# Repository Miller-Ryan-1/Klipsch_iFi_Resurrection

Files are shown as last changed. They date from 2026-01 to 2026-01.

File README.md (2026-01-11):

# Klipsch iFi Resurrection  
### Salvaging a Klipsch iFi 2.1 System & Adding Bluetooth

---

## Summary

This project revives a broken Klipsch iFi 2.1 speaker system whose proprietary iPod dock failed, rendering the entire system unusable. By emulating the dock’s logic using a simple microcontroller and discrete components, the system powers on and functions normally again.

Bluetooth audio support was added as a modern input, restoring full usability while preserving the system’s original (and still outstanding) sound quality.

This repository contains:
- Arduino firmware
- Hardware wiring details
- Reference documentation
- STL files for a custom 3D-printed enclosure
- Build photos from two hardware revisions

---

## Background

I’ve been hauling this Klipsch iFi system around since mid-2006. I originally intended to buy a Bose SoundDock, but a Best Buy salesman directed me toward the Klipsch instead. It was more expensive (about $100 more), and far heavier, but sounded dramatically better. And it got LOUD.

The system followed me across continents. Fans of *Club Jesuitenfahrt 7* in Amberg, Germany would dance and drank the night away to these speakers.

Eventually, the proprietary dock became the system’s Achilles’ heel. Newer iPhones no longer fit properly, and when the dock finally failed electrically, the entire subwoofer refused to power on—even when using the auxiliary input. Without a working dock, the system was bricked.

There is no public documentation on how to repair or bypass this dock logic. This was a one-off product for Klipsch, and very little information was ever released.

Using modern LLMs, I was finally able to identify the key control IC (LM1973) and replicate the dock’s behavior externally. This repository documents that solution.

---

## Repository Structure

```text
Klipsch_iFi_Resurrection/
│
├── klipsch_reviver/
│   └── klipsch_reviver.ino
│
├── case_stil_files/
│   ├── Klipsch_Case_Base.stl
│   └── Klipsch_Case_Cover.stl
│
├── pictures/
│   ├── DIN-9_mockup.JPG
│   ├── DIN-9_wires.JPG
│   ├── main_board.JPG
│   ├── sub_insides.JPG
│   ├── v1.JPG
│   ├── v1_closeup.JPG
│   ├── v1_on.JPG
│   ├── v2.JPG
│   └── v2_connections.JPG
│
├── DIN-9 Pinout.pdf
├── LM1973_info.pdf
└── README.md
```

---

## Bill of Materials (BOM)

| Qty | Component (and link to example) |
|----:|:---|
| 1 | [Arduino-compatible 5 V microcontroller](https://www.amazon.com/AYWHP-ATmega328P-Microcontroller-Compatible-Arduino/dp/B0DFGQW2ZY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) |
| 2 | 100 kΩ resistors |
| 6 | 10 kΩ resistors |
| 2 | 100 Ω resistors |
| 1 | 1 kΩ resistor |
| 1 | 10 µF electrolytic capacitor |
| 2 | 0.1 µF ceramic capacitors |
| 1 | 47 nF ceramic capacitor |
| 2 | 1 nF ceramic capacitors |
| 1 | [Male DIN-9 cable](https://www.amazon.com/dp/B0C9QGQHK2?ref_=ppx_hzsearch_conn_dt_b_fed_asin_title_1&th=1) |
| 1 | [12 V → 5 V buck converter](https://www.amazon.com/dp/B08VHZJ3C8?ref_=ppx_hzsearch_conn_dt_b_fed_asin_title_1&th=1) |
| 4 | [Normally-open momentary push buttons](https://www.amazon.com/DAOKI-Miniature-Momentary-Tactile-Quality/dp/B01CGMP9GY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) |
| 1 | [LED (power indicator)](https://www.amazon.com/OWOFYDR-diffused-Electronic-Component-Indicator/dp/B0DHX8Q58F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) |
| 1 | [Breadboard](https://www.amazon.com/ELEGOO-Breadboard-Solderless-Breadboards-Electronics/dp/B0CYPVMK9J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) |
| 1 | [Ferrite core](https://www.amazon.com/20pcs-Clip-Ferrite-Suppressor-Diameter/dp/B0CSXZWGD6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) |
| 1 | Project enclosure |

**Optional (but recommended):**
- Bluetooth audio module (with external antenna connector)
- Bluetooth antenna (external)
- RCA-to-3.5 mm or 3.5 mm-to-3.5 mm audio cable

*$$ Note: The total cost is hard to pinpoint, since many components cannot be purchased in single quantities, but it probably cost me less than $40, to include Bluetooth Audio Module and raw PLA filament (material I used for the box).*

---

## Procedure

### 0) Optional: Inspect the Subwoofer Internals

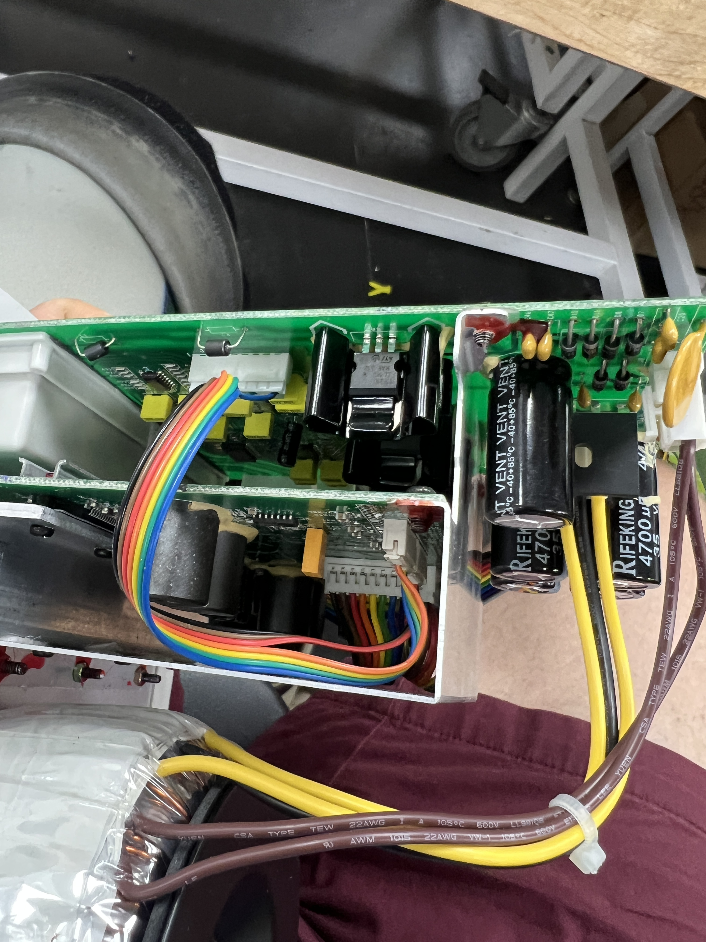
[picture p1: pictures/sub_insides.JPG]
Subwoofer internals


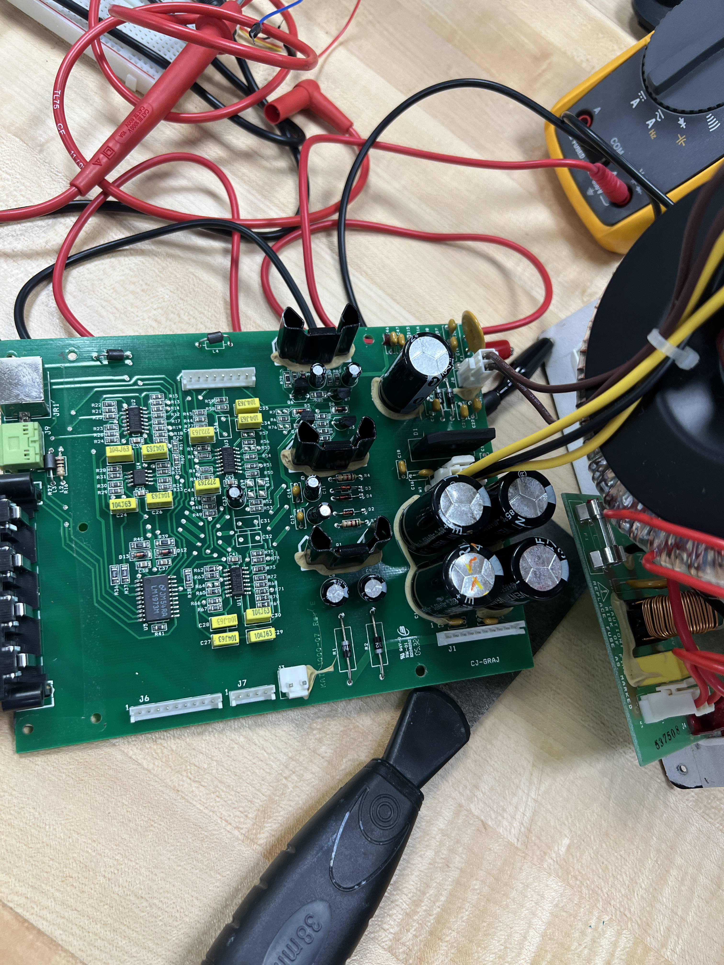
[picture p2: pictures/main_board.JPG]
Main board
  

I initially opened the subwoofer to understand the signal flow and verify component health—especially the LM1973 digital volume control IC that the dock communicates with.

In hindsight, this step was unnecessary; all internal components were functional.

**Warning:** The subwoofer contains large capacitors capable of delivering a severe shock. If opening:
- Unplug and allow the unit to sit for several hours
- Discharge large capacitors with an insulated tool
- Avoid touching exposed circuitry

---

### 1) Prepare the DIN-9 Cable

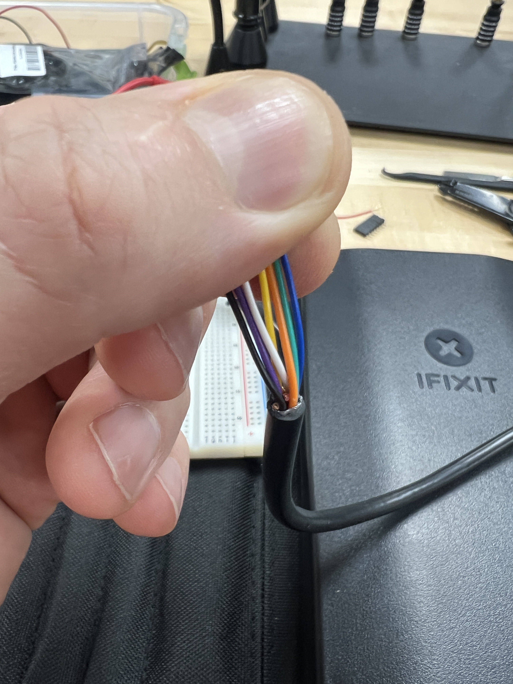
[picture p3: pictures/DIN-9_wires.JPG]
DIN-9 wires


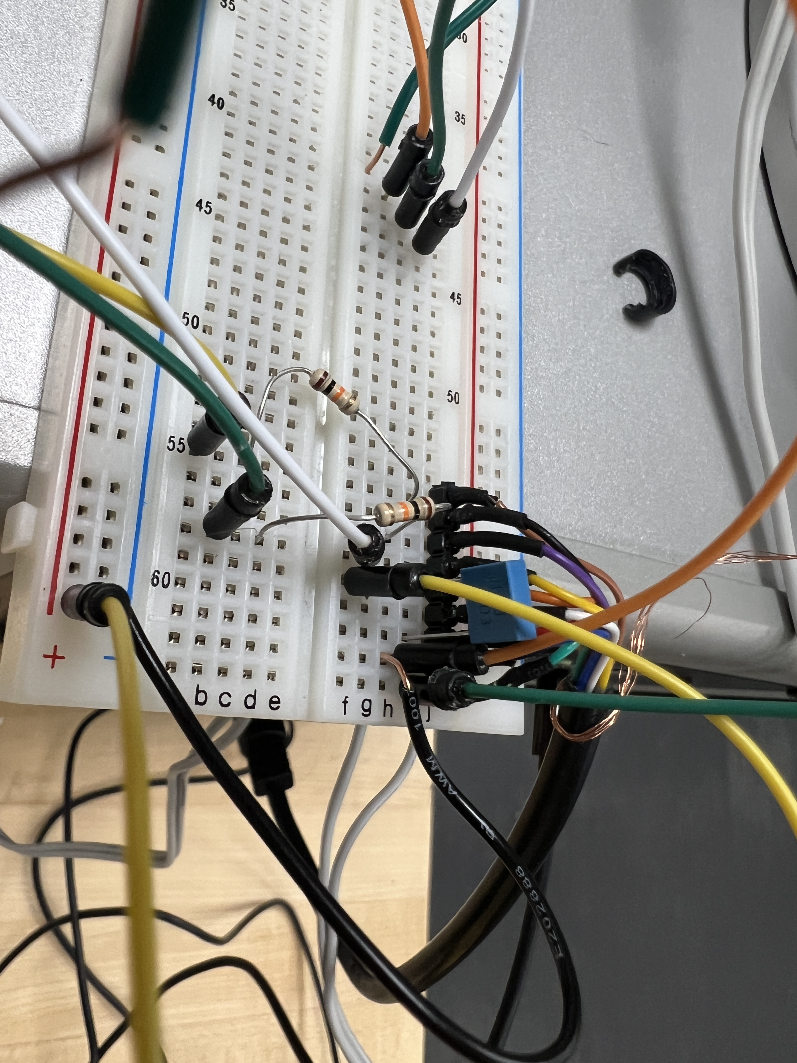
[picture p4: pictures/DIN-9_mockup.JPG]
DIN-9 mockup
  

Cut the DIN-9 cable approximately 12 inches from the male plug. Strip the outer sheath to expose:
- 9 internal conductors
- Foil shielding
- Bare braided ground wire

Keep exposed wire lengths as short as possible to minimize noise.

Use a multimeter to identify each conductor’s pin. Do **not** rely on wire colors.  

Speaking of colors, the colors in the diagram below is NOT related to wire colors, but rather functional pin groupings.

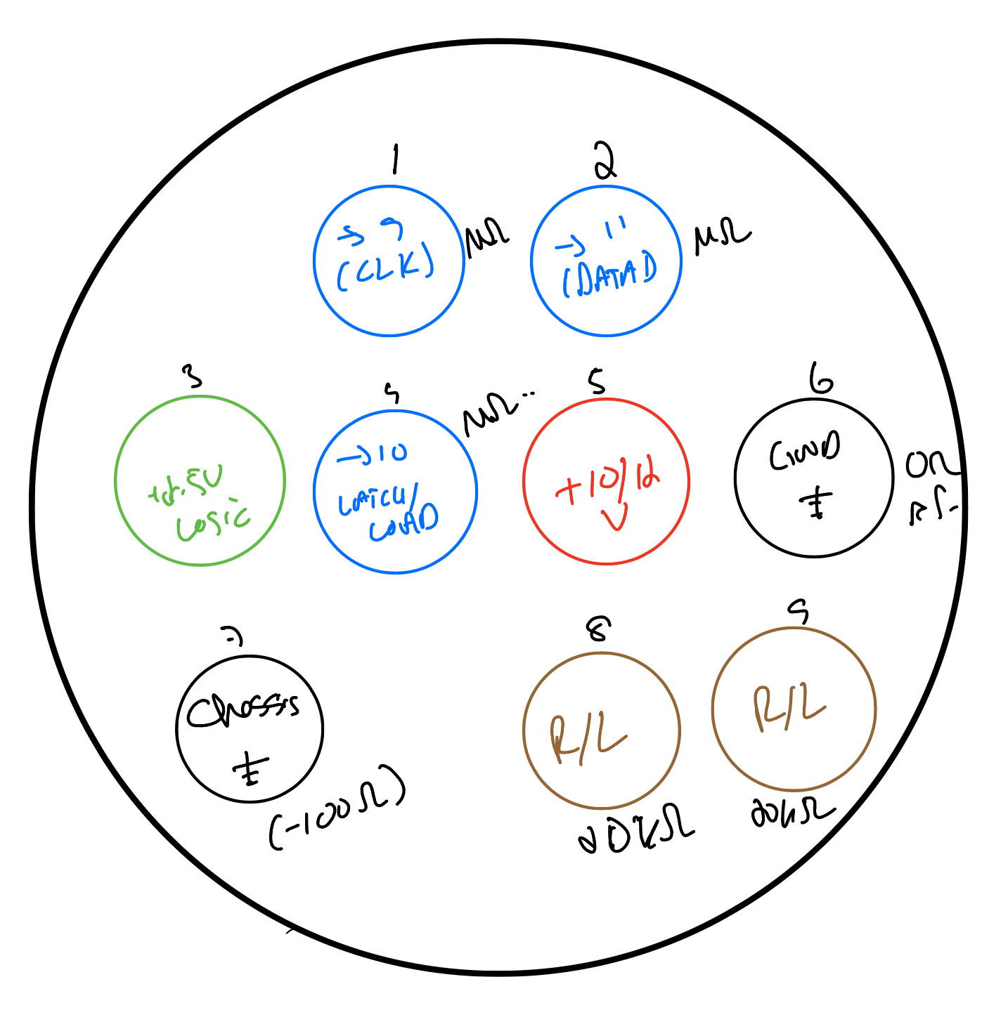
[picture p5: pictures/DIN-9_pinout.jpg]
DIN-9 pinout


#### Pin Mapping

| Pin | Function |
|----:|---|
| 1 | LM1973 CLK |
| 2 | LM1973 DATA |
| 3 | 2.5 V logic |
| 4 | LM1973 LATCH |
| 5 | 12 V supply |
| 6 | Logic ground |
| 7 | Chassis ground |
| 8 | Sense A |
| 9 | Sense B |

---

### 2) Sense Wake & Power Enable

- Connect Pin 8 → Pin 3 through **100 Ω**
- Connect Pin 8 → Pin 6 (GND) through **100 kΩ + 1 nF**
- Repeat for Pin 9

At this point, the sub should power on (audible relay click and faint hum).  
Turn off before proceeding.

---

### 3) Power Regulation

- Feed Pin 5 (12 V) into the buck converter
- Generate a clean 5 V rail
- Add between the 5V rail and ground:
  - 10 µF electrolytic capacitor (polarity matters!)
  - 0.1 µF ceramic capacitor
- Wrap a ferrite core around the buck output leads

---

### 4) LM1973 Digital Control

Reference: `LM1973_info.pdf`

To generate 2.5 V logic from Arduino GPIO, use 10 kΩ / 10 kΩ voltage dividers. That means connect each of the indicated DIN pins to ground via a 10 kΩ resistor, and also connect it to the indicated Arduino pins through 10 kΩ resistors.

| DIN Pin | Arduino Pin |
|---:|---:|
| CLK | D4 |
| DATA | D3 |
| LATCH | D2 |

---

### 5) Grounds & Noise Control

- Bridge Logic GND ↔ Chassis GND using:
  - 100 Ω resistor
  - 0.1 µF capacitor
- Remove unused braided shielding

---

### 6) Controls & Indicators

- LED powered directly from 5 V through a **1 kΩ** resistor
- Buttons wired to GPIO with internal pull-ups:

| Function | Arduino Pin |
|---:|---:|
| Volume Up | D7 |
| Volume Down | D6 |
| Sub Up | D9 |
| Sub Down | D8 |

---

### 7) Bluetooth Audio

- Power the Bluetooth module from the 5 V rail
- Connect audio output to the subwoofer’s AUX input
- Pair once; no special firmware handling required

---

### 8) Circuit Schematic

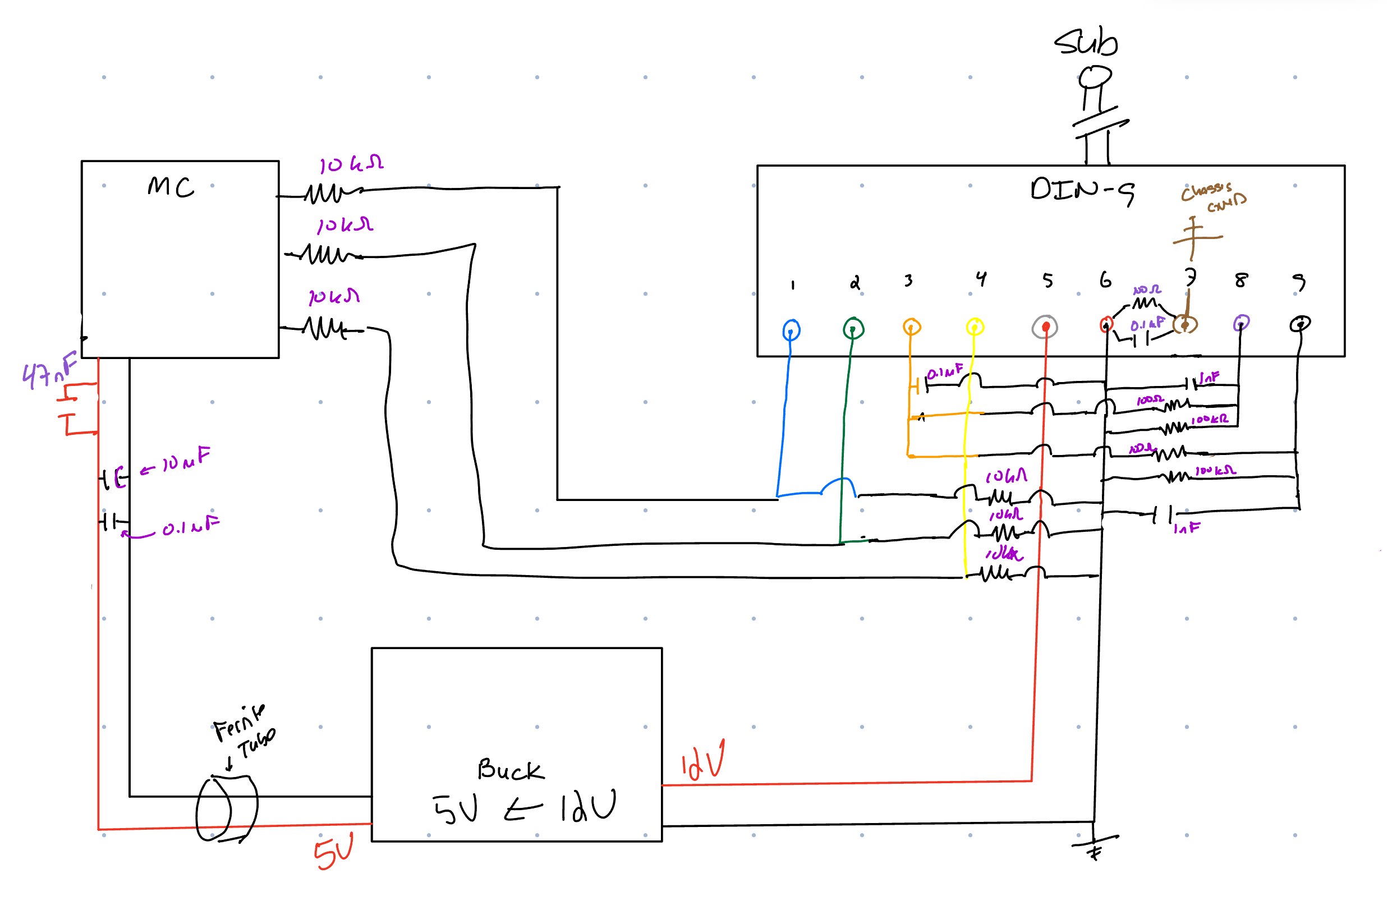
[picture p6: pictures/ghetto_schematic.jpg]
Diagram


---
### 9) Programming & Enclosure

Flash `klipsch_reviver.ino` using the Arduino IDE.  
A microcontroller with native USB is strongly recommended to avoid FTDI headaches.

---

## Build Revisions

### Version 1 – Off-the-Shelf Project Box

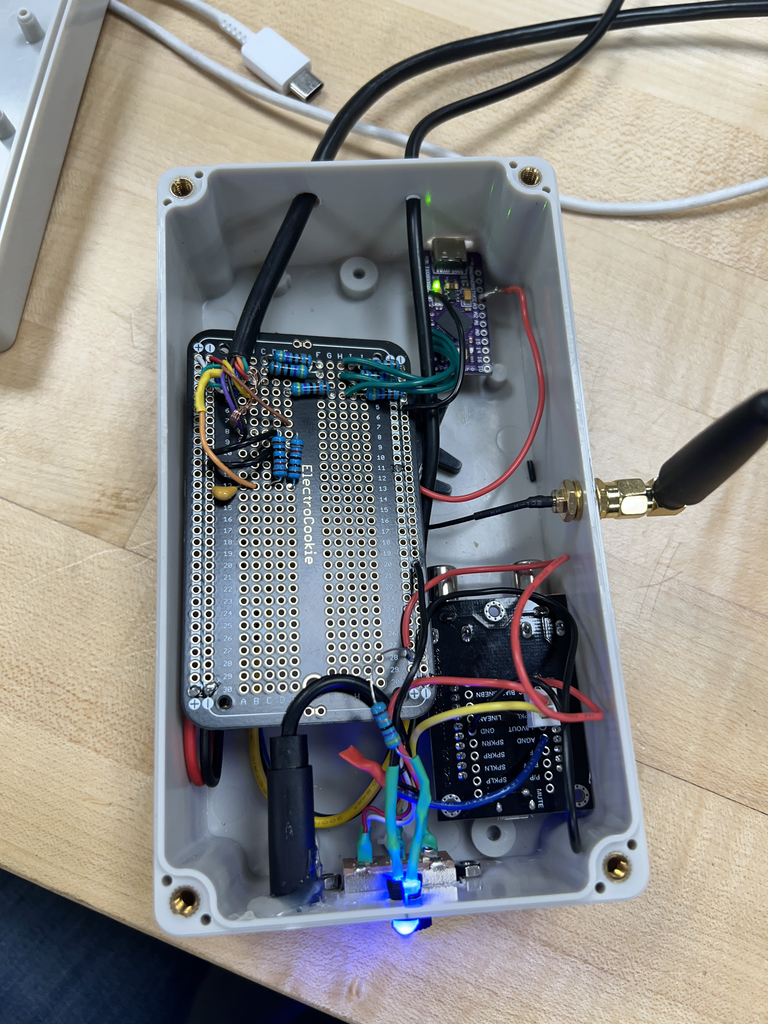
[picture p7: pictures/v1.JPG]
Version 1
  
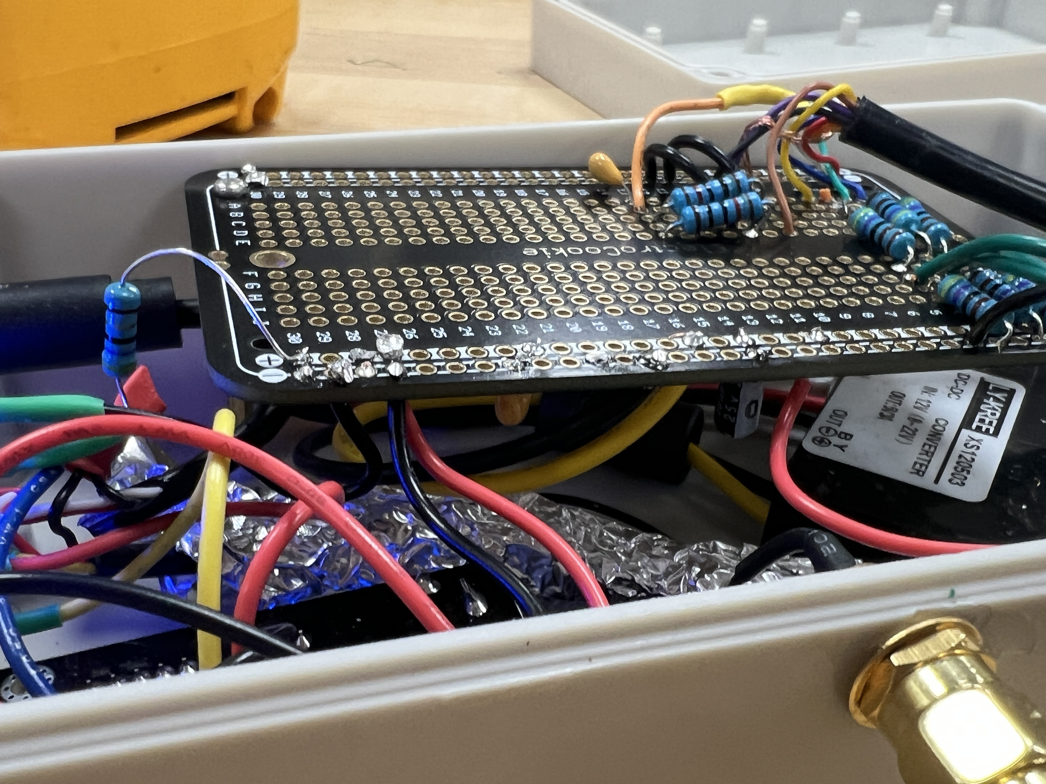
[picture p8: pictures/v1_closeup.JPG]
Version 1 close-up
  
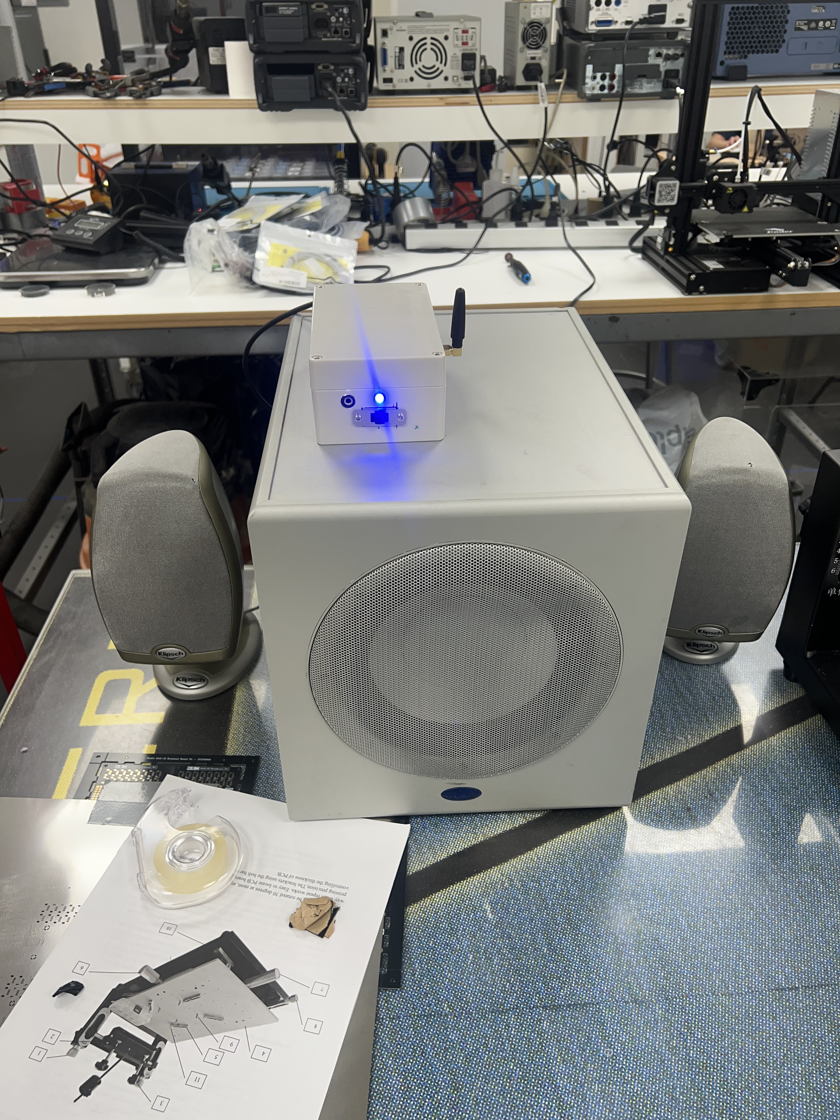
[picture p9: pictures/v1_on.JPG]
Version 1 powered


This version worked but suffered from cramped wiring and ground loop noise.

---

### Version 2 – Custom 3D-Printed Enclosure

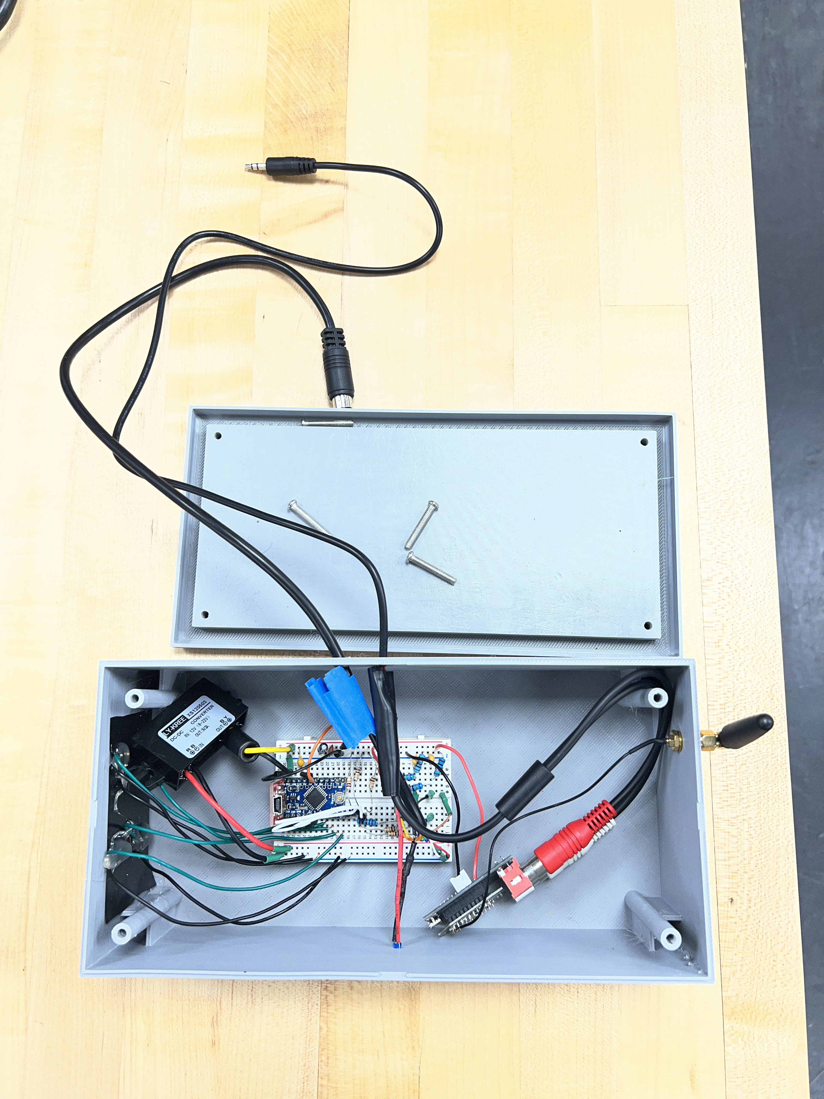
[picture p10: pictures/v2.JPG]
Version 2
  
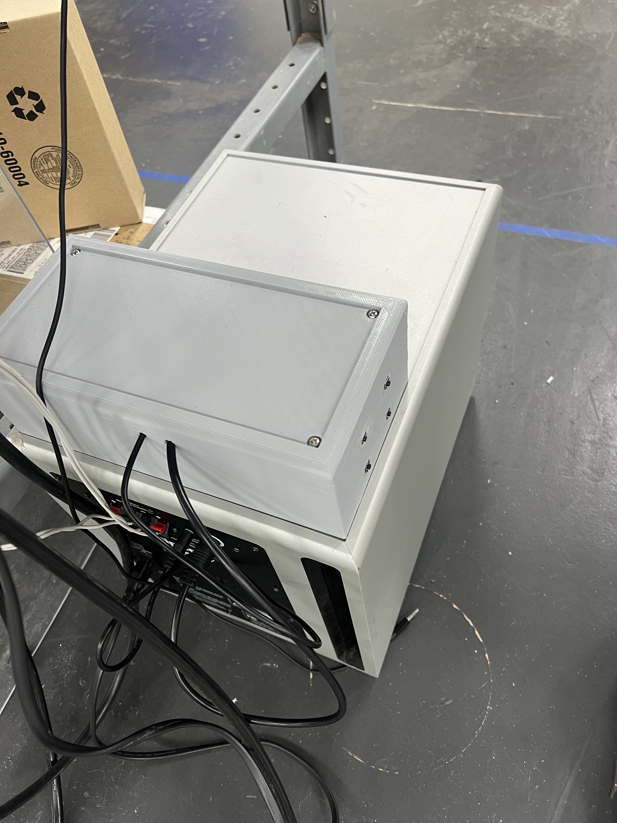
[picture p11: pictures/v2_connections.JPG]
Version 2 wiring


This version uses a cleaner layout and a custom 3D-printed enclosure.  
Ground loops were eliminated entirely.

STL files are provided in `case_stil_files/`.

---

## Status

The revived system:
- Powers on normally
- Retains original sound quality
- Supports modern audio sources
- Operates without the original dock

---

## Disclaimer

This project is not affiliated with Klipsch.  
Provided for educational and personal repair purposes only.

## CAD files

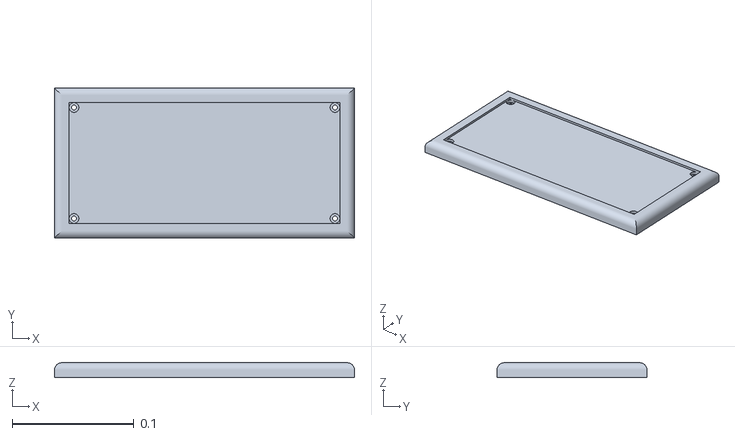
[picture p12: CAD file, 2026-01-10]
case_stl_files/Klipsch_Case-Cover.stl
0.246 x 0.123 x 0.012

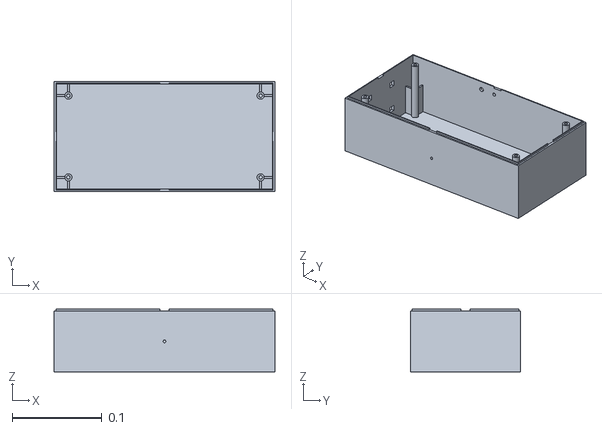
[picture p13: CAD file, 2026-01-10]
case_stl_files/Klipsch_Case-Base.stl
0.246 x 0.123 x 0.07

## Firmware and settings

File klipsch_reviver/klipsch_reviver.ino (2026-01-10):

/*
This code is used to replace the functions of the Klipsch iFi 2.1
system's dock.  Loss of dock function represents a critical failure point for 
this speaker system without the following code, along with some additional
hardware discussed here [[link to github repo with additional info]]

It uses the Serial Monitor to submit the commands originally sent over by the
dock's logic. Thus, a serial connection to actual chip is required to set the volume
(to be updated in next version!). The commands can be found by typing "Help" into the
Serial.

* * * * * Update * * * * *
In addition to serial monitor commands, user friendlier buttons placed on the device case
can now be used to increment or decrement the attentuation levels, one set for the satellite
speaker volume, and one set for the sub volume (effectively bass control).
* * * * * * * * * * * * * *

Important Notes:
  The OEM dock interacts with a LM1973M chip on the PreAmp Board.  It sends
  bit (1s and 0s) signals to the chip to control the overall volume of the satellite 
  speakers and the subwoofer.  For this code the mappings are:
  LM1973M Pins Connected to Microcontroller (LM1973M -> Microcontroller Pin ):
    CLK   -> D4
    DATA  -> D3
    LATCH -> D2
  The pinout diagram and bit-bang info for LM1973M can be found with the supporting 
  materials.
  
  LM1973 Channels:
    0x00 = Ch1 (Sat L), 0x01 = Ch2 (Sat R), 0x02 = Ch3 (Sub)

  Default Settings:
    Satellites = 0x14 (≈ -20 dB), Sub = 0x14 (≈ -20 dB)
    *used these high attenuation setting as default due to ground loop issues to be fixed

  Serial Monitor: 9600 baud
  Commands:
    Gross Volume Control: 'MUTE' / 'FULL' / 'SATFULL' / 'SUBFULL'
    Granular Volume Control: 'SATL n' / 'SUBL n' / 'ALL n'   (where n  =0..9 => ATT_TABLE[n])
    Channel Address: 'SAT xx' / 'SUB xx' / 'ALL xx'   (hex byte, e.g., 1E, 4E, 00, FF)
    Save: 'SAVE'    (write current to EEPROM)

By: R Miller
Last Updated: Jan 2026
*/

// To store the last volume settings in memory to apply on system startup.
#include <EEPROM.h>

// ---------- Button debouncer types/prototypes (must be above functions in Arduino) ----------
struct ButtonEdge {
  uint8_t pin;
  bool stableState;              // last debounced read (true=HIGH, false=LOW)
  bool lastReading;
  unsigned long lastChangeMs;
};

// -------------------------------------------------------------------------------------------

// Map LM1973M pins to Microcontroller Pins
const uint8_t PIN_CLK  = 4;
const uint8_t PIN_DATA = 3;
const uint8_t PIN_LOAD = 2;

// Volume Control Buttons
const uint8_t V_UP_PIN   = 7;    // <-- put real pin number here
const uint8_t V_DOWN_PIN = 6;  // <-- put real pin number here
const uint8_t S_UP_PIN   = 9;    // <-- put real pin number here
const uint8_t S_DOWN_PIN = 8;  // <-- put real pin number here

// Debounce timing (ms)
const unsigned long BTN_DEBOUNCE_MS = 35;
// -----------------------------------------------------------------------------

// Map channels (L & R satellite speakers and subwoofer) to their LM1973M hex bit codes.
const uint8_t ADDR_CH1 = 0x00;
const uint8_t ADDR_CH2 = 0x01;
const uint8_t ADDR_CH3 = 0x02;

// Core volume/attenuation codes:
// !Note: 0 dB is max volume, negative numbers represent attenuation from that level
const uint8_t CODE_FULL_VOL = 0x00; // 0 dB
const uint8_t CODE_DEEPEST  = 0x4E; // -76 dB
const uint8_t CODE_MUTE_1   = 0x4F; // first mute code
const uint8_t CODE_MUTE_FF  = 0xFF; // explicit 0xFF mute

// Ten useful attenuation (volume) steps between 0x00 and 0x4F (max and first mute)
const uint8_t ATT_TABLE[10] = {
  0x06, 0x0C, 0x12, 0x18, 0x1E,
  0x24, 0x2A, 0x30, 0x3C, 0x48
};

// Defaults (first run) and presets the live “last known” in case nothing is stored
// to rewrite it later:
const uint8_t DEFAULT_SAT = 0x10; // 16  -> ~ -8 dB
const uint8_t DEFAULT_SUB = 0x10; // 16   -> ~ -8 dB
uint8_t lastSat = DEFAULT_SAT;
uint8_t lastSub = DEFAULT_SUB;

// EEPROM layout
const int     EEP_MAGIC_ADDR = 0;
const int     EEP_SAT_ADDR   = 1;
const int     EEP_SUB_ADDR   = 2;
const uint8_t EEP_MAGIC      = 0xA7;

// ---------- Bit Banger! ----------
// These two little functions, lo and hi, send the 0 or 1 bit respectively
static inline void lo(uint8_t p){ digitalWrite(p, LOW); }
static inline void hi(uint8_t p){ digitalWrite(p, HIGH); }

// shiftByteMSB creates the bit stream that sets volume using the hi & lo functions
void shiftByteMSB(uint8_t b){
  for (int i = 7; i >= 0; --i){
    lo(PIN_CLK);
    ((b >> i) & 1) ? hi(PIN_DATA) : lo(PIN_DATA);
    delayMicroseconds(1);
    hi(PIN_CLK);                 // rising edge clocks bit
    delayMicroseconds(1);
  }
  lo(PIN_CLK);
}

// lm1973_write uses the shiftByteMSB function to create commands, then sends it to chip
void lm1973_write(uint8_t addr, uint8_t data){
  lo(PIN_LOAD);
  delayMicroseconds(1);
  shiftByteMSB(addr);
  shiftByteMSB(data);
  hi(PIN_LOAD);
  delayMicroseconds(2);
  lo(PIN_LOAD);
  lo(PIN_DATA);
}

// ---------- Channel Selection Functions ----------
// These helper functions bundle settings to different addresses
void setSatellites(uint8_t data){
  lm1973_write(ADDR_CH1, data);
  lm1973_write(ADDR_CH2, data);
  lastSat = data;
}
void setSub(uint8_t data){
  lm1973_write(ADDR_CH3, data);
  lastSub = data;
}
void setBoth(uint8_t satData, uint8_t subData){
  setSatellites(satData);
  setSub(subData);
}

// Button Step Functions - Note: got lazy and used ChatGPT so these functions aren't human documented as well
static inline uint8_t clampAtt(uint8_t v){
  // Normalize any mute code to deepest attenuation before stepping
  if (v == CODE_MUTE_FF || v >= CODE_MUTE_1) v = CODE_DEEPEST;

  if (v < CODE_FULL_VOL)  v = CODE_FULL_VOL;
  if (v > CODE_DEEPEST)   v = CODE_DEEPEST;
  return v;
}

void stepSat(int8_t delta){
  uint8_t v = clampAtt(lastSat);

  // delta = -1 => reduce attenuation (louder)
  // delta = +1 => increase attenuation (quieter)
  int16_t nv = (int16_t)v + (int16_t)delta;
  if (nv < (int16_t)CODE_FULL_VOL) nv = CODE_FULL_VOL;
  if (nv > (int16_t)CODE_DEEPEST)  nv = CODE_DEEPEST;

  setSatellites((uint8_t)nv);
  saveSettings();

  Serial.print("BTN Sat -> 0x"); Serial.println(lastSat, HEX);
}

void stepSub(int8_t delta){
  uint8_t v = clampAtt(lastSub);

  int16_t nv = (int16_t)v + (int16_t)delta;
  if (nv < (int16_t)CODE_FULL_VOL) nv = CODE_FULL_VOL;
  if (nv > (int16_t)CODE_DEEPEST)  nv = CODE_DEEPEST;

  setSub((uint8_t)nv);
  saveSettings();

  Serial.print("BTN Sub -> 0x"); Serial.println(lastSub, HEX);
}

bool buttonPressed(ButtonEdge &b){
  bool reading = (digitalRead(b.pin) == HIGH);

  if (reading != b.lastReading){
    b.lastChangeMs = millis();
    b.lastReading = reading;
  }

  if ((millis() - b.lastChangeMs) > BTN_DEBOUNCE_MS){
    if (reading != b.stableState){
      b.stableState = reading;

      // We use INPUT_PULLUP; pressed = LOW => stableState becomes false
      if (b.stableState == false){
        return true; // falling edge (HIGH->LOW) == press
      }
    }
  }

  return false;
}

// Button state holders
ButtonEdge btnVUp   = { V_UP_PIN,   true, true, 0 };
ButtonEdge btnVDown = { V_DOWN_PIN, true, true, 0 };
ButtonEdge btnSUp   = { S_UP_PIN,   true, true, 0 };
ButtonEdge btnSDown = { S_DOWN_PIN, true, true, 0 };
// -----------------------------------------------------------------------------

// ---------- Mute Functions ----------
// muteChannelAllWays mutes then sets the system to lowest volume setting
void muteChannelAllWays(uint8_t addr){
  lm1973_write(addr, CODE_MUTE_1);
  lm1973_write(addr, CODE_MUTE_FF);
  lm1973_write(addr, CODE_DEEPEST);
}
// muteAll is self explanatory, using muteChannelAllWays
void muteAll(){
  muteChannelAllWays(ADDR_CH1);
  muteChannelAllWays(ADDR_CH2);
  muteChannelAllWays(ADDR_CH3);
  lastSat = CODE_MUTE_1;
  lastSub = CODE_MUTE_1;
}

// ---------- EEPROM - Volume Memory Management ----------
// Save and load settings using EEPROM library
void saveSettings(){
  EEPROM.update(EEP_MAGIC_ADDR, EEP_MAGIC);
  EEPROM.update(EEP_SAT_ADDR,   lastSat);
  EEPROM.update(EEP_SUB_ADDR,   lastSub);
}
void loadSettings(){
  if (EEPROM.read(EEP_MAGIC_ADDR) == EEP_MAGIC){
    lastSat = EEPROM.read(EEP_SAT_ADDR);
    lastSub = EEPROM.read(EEP_SUB_ADDR);
  } else {
    lastSat = DEFAULT_SAT;
    lastSub = DEFAULT_SUB;
    saveSettings();
  }
}

// ---------- Serial Control ----------

// handleCmd executes the inputed command string by executing the command and then 
// replaying the execution outcome to the serial monitor
void handleCmd(String s){
  s.trim(); s.toUpperCase();

  if (s == "MUTE"){ muteAll(); Serial.println("All -> MUTE"); return; }
  if (s == "FULL"){ setBoth(CODE_FULL_VOL, CODE_FULL_VOL); Serial.println("All -> 0x00"); return; }
  if (s == "SATFULL"){ setSatellites(CODE_FULL_VOL); Serial.println("Sat -> 0x00"); return; }
  if (s == "SUBFULL"){ setSub(CODE_FULL_VOL); Serial.println("Sub -> 0x00"); return; }
  if (s == "SAVE"){ saveSettings(); Serial.println("Saved."); return; }

  if (s.startsWith("SATL")){
    int n = s.substring(4).toInt();
    if (n>=0 && n<10){ setSatellites(ATT_TABLE[n]); Serial.print("Sat -> table["); Serial.print(n); Serial.println("]"); return; }
  }
  if (s.startsWith("SUBL")){
    int n = s.substring(4).toInt();
    if (n>=0 && n<10){ setSub(ATT_TABLE[n]); Serial.print("Sub -> table["); Serial.print(n); Serial.println("]"); return; }
  }
  if (s.startsWith("ALLL")){
    int n = s.substring(4).toInt();
    if (n>=0 && n<10){ setBoth(ATT_TABLE[n], ATT_TABLE[n]); Serial.print("All -> table["); Serial.print(n); Serial.println("]"); return; }
  }

  if (s.startsWith("SAT ")){
    uint8_t v = (uint8_t) strtoul(s.substring(4).c_str(), nullptr, 16);
    setSatellites(v); Serial.print("Sat -> 0x"); Serial.println(v, HEX); return;
  }
  if (s.startsWith("SUB ")){
    uint8_t v = (uint8_t) strtoul(s.substring(4).c_str(), nullptr, 16);
    setSub(v);        Serial.print("Sub -> 0x"); Serial.println(v, HEX); return;
  }
  if (s.startsWith("ALL ")){
    uint8_t v = (uint8_t) strtoul(s.substring(4).c_str(), nullptr, 16);
    setBoth(v, v);    Serial.print("All -> 0x"); Serial.println(v, HEX); return;
  }

  Serial.println("Cmds: MUTE | FULL | SATFULL | SUBFULL | SATL n | SUBL n | ALLL n | SAT xx | SUB xx | ALL xx | SAVE");
}

// ---------- Setup and Loop ----------
void setup(){
  // Set all microcontroller to LM1973M chip pins to output
  pinMode(PIN_CLK,  OUTPUT);
  pinMode(PIN_DATA, OUTPUT);
  pinMode(PIN_LOAD, OUTPUT);
  lo(PIN_CLK); lo(PIN_DATA); lo(PIN_LOAD);   // Initialize all to low/0

  // NEW: button inputs (normally-open to GND, use internal pullups)
  pinMode(V_UP_PIN,   INPUT_PULLUP);
  pinMode(V_DOWN_PIN, INPUT_PULLUP);
  pinMode(S_UP_PIN,   INPUT_PULLUP);
  pinMode(S_DOWN_PIN, INPUT_PULLUP);

  Serial.begin(9600);

  loadSettings();          // recall last
  delay(1200);             // rails/relays settle

  // Apply remembered settings to wake on power-up
  setBoth(lastSat, lastSub);

  saveSettings();          // ensure EEPROM has current values

  // Print curent volume on startup
  Serial.print("Boot applied: SAT=0x"); Serial.print(lastSat, HEX);
  Serial.print(" SUB=0x"); Serial.println(lastSub, HEX);
}

void loop(){
  // NEW: button handling (one step per press, debounced)
  if (buttonPressed(btnVUp))   { stepSat(-1); } // louder satellites
  if (buttonPressed(btnVDown)) { stepSat(+1); } // quieter satellites
  if (buttonPressed(btnSUp))   { stepSub(-1); } // louder sub
  if (buttonPressed(btnSDown)) { stepSub(+1); } // quieter sub

  if (Serial.available()){
    String line = Serial.readStringUntil('\n');
    handleCmd(line);
    saveSettings();        // auto-save after each command
  }

  // TA nudge required to sometimes "wake" the thing up
  static bool resent = false;
  if (!resent && millis() > 4000){
    setBoth(lastSat, lastSub);  // final wake resend
    resent = true;
  }
}
